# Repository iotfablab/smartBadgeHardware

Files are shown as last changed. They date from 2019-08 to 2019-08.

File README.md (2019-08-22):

# smartBadgeHardware
This repository holds the hardware design files for the iotfablab Smart Badge.

The hardware layout has been adapted from the "Sparkfun ESP-32-Thing Plus" (https://www.sparkfun.com/products/14689) and the "Waveshare e-Paper ESP32 Driver Board" (https://www.waveshare.com/e-paper-esp32-driver-board.htm).

It is designed to work with 
* the Waveshare 2.9 inch raw e-Paper Display (https://www.waveshare.com/2.9inch-e-Paper.htm) and 
* a 1 cell 3.7V LiPo battery with 2mm JST plug (e.g. https://www.exp-tech.de/zubehoer/batterien-akkus/lipo-akkus/9365/lipo-akku-750mah-3.7-v-2-mm-jst?c=1191).

# License
<br />This work is licensed under a <a rel="license" href="http://creativecommons.org/licenses/by-sa/4.0/">Creative Commons Attribution-ShareAlike 4.0 International License</a>.

# Contact
This project has been developed as an internal project of the IoT-Fablab (www.iotfablab.eu) at BIBA - Bremer Institut für Produktion und Logistik GmbH at the University of Bremen.

For more information on the project or our lab, please feel free to contact us via info@iotfablab.eu

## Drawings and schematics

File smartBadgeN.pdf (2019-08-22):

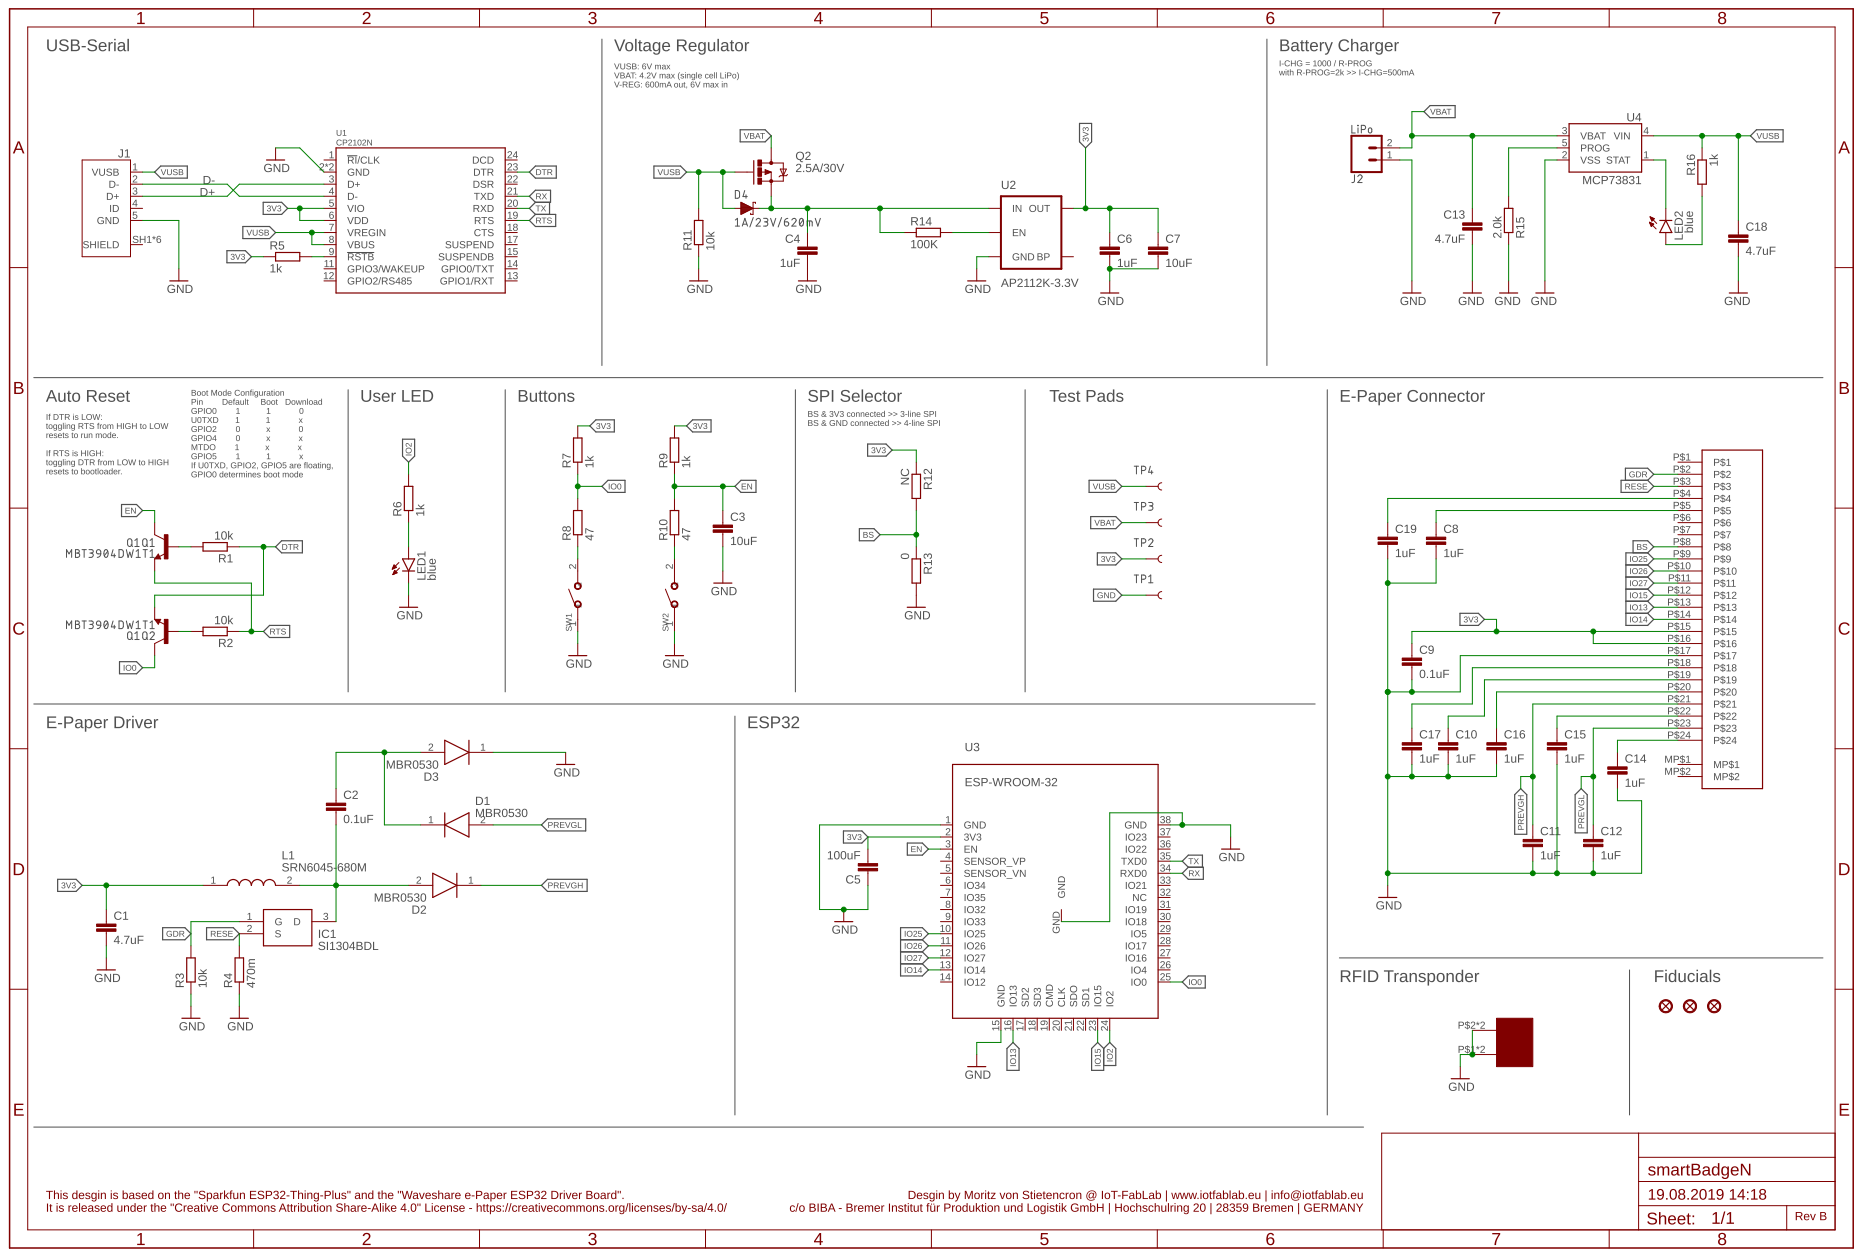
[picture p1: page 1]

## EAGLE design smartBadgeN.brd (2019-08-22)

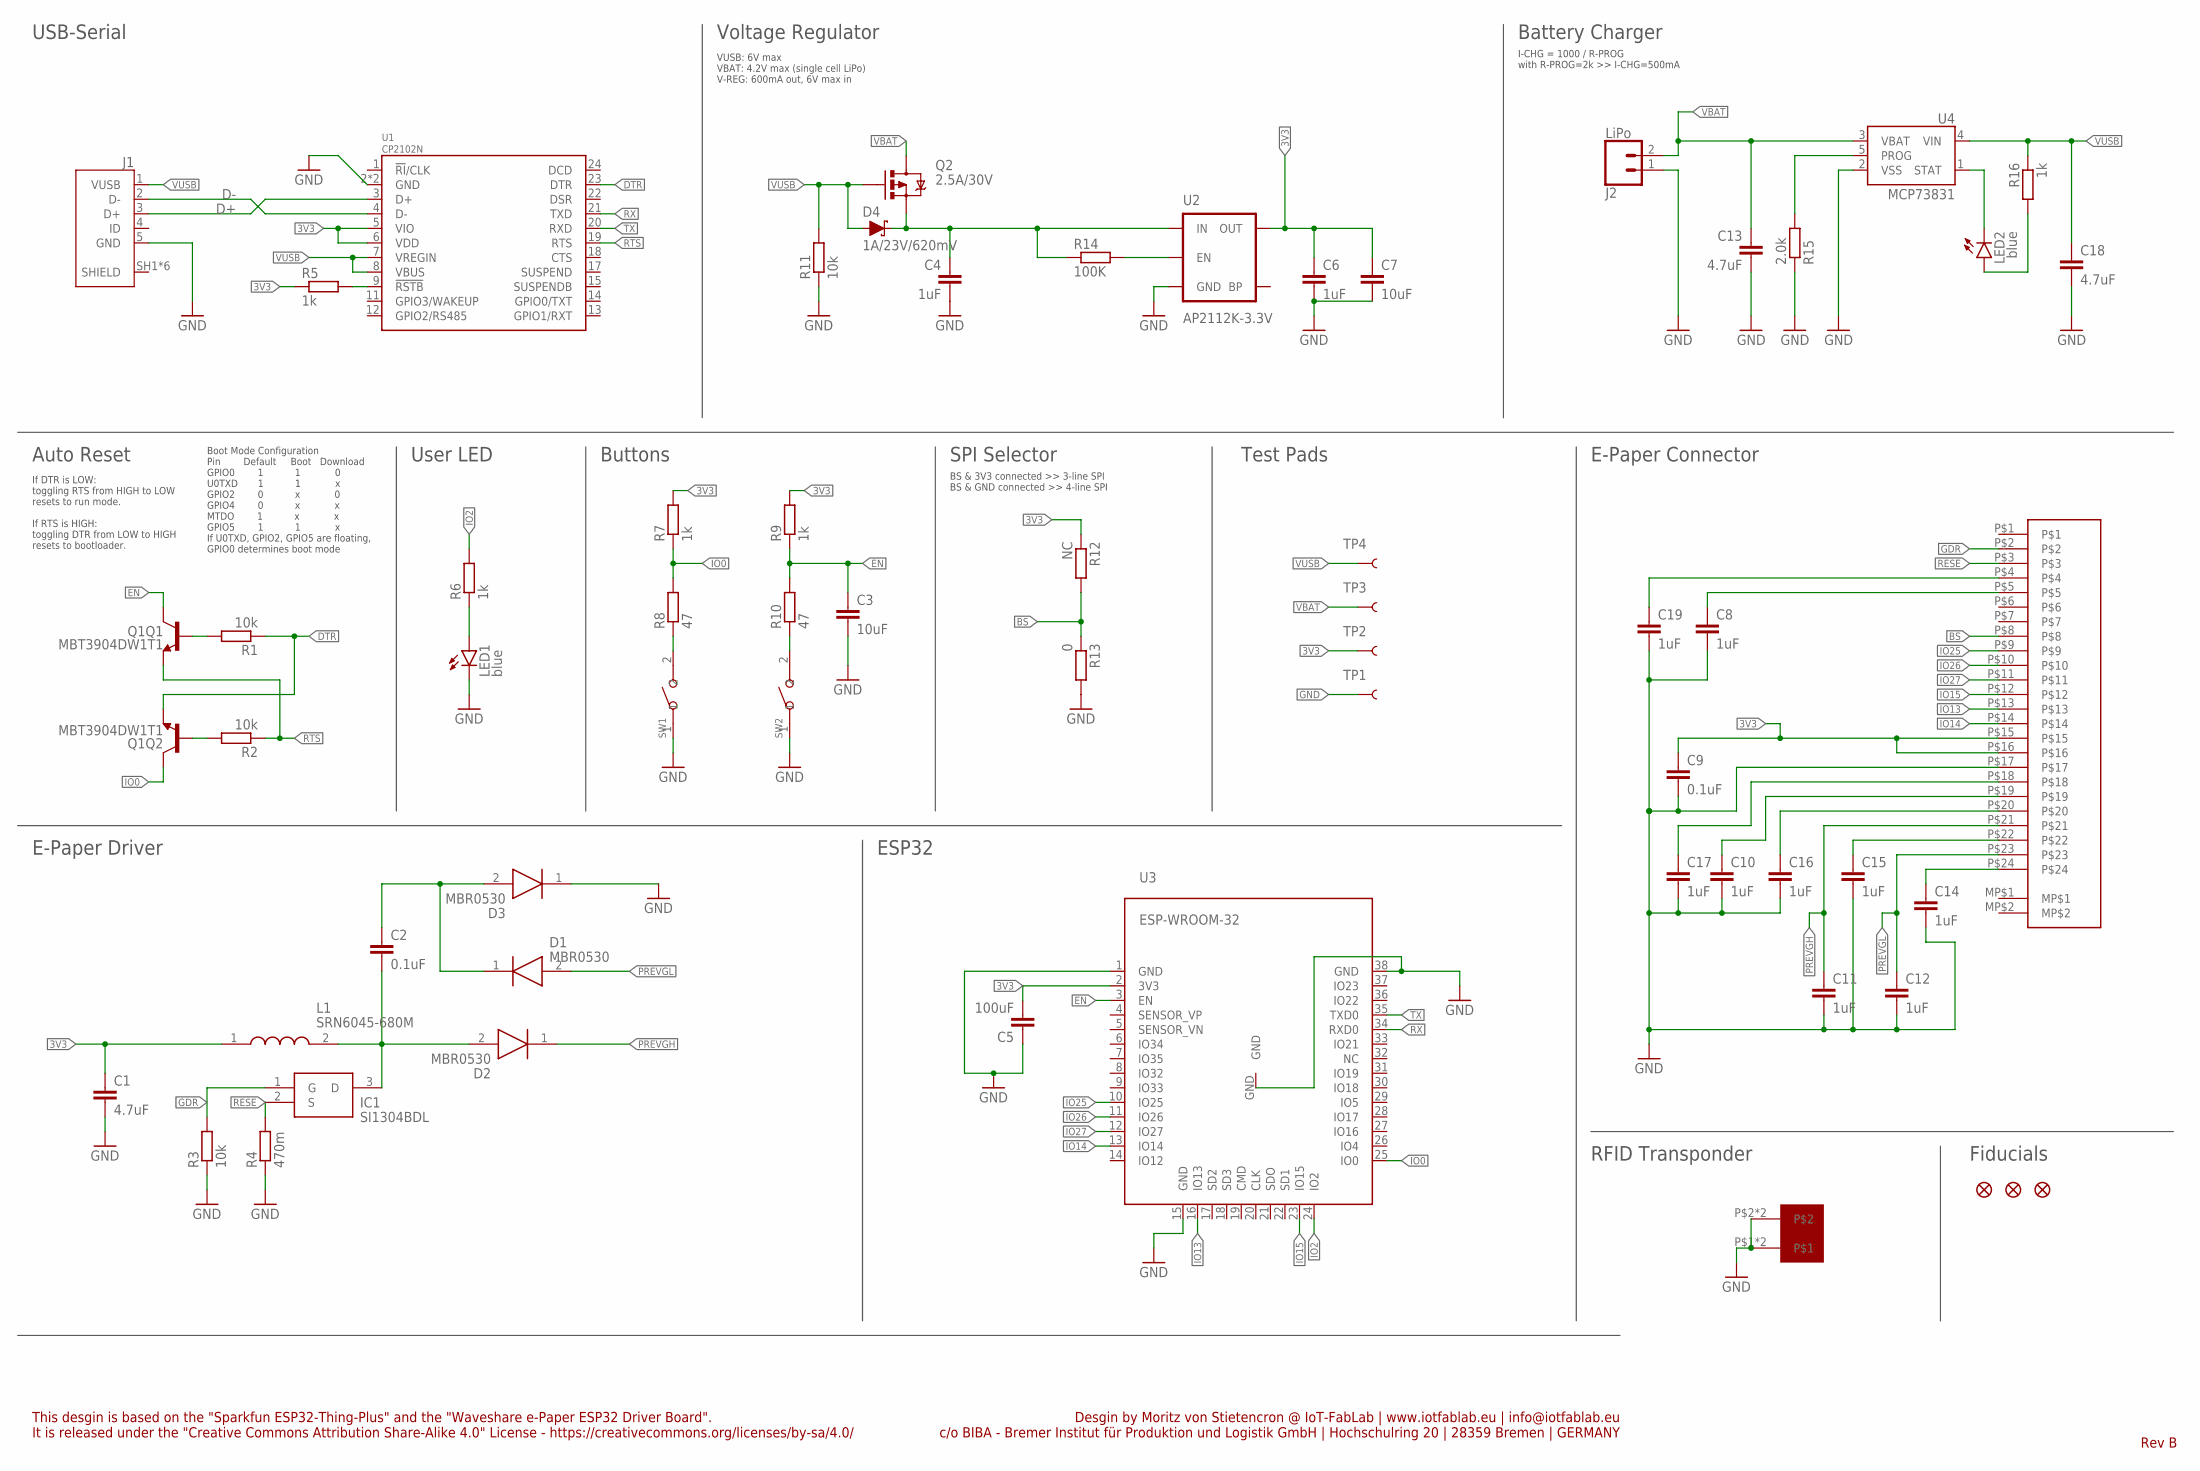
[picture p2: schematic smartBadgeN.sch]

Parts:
C1, C13, C18: 4.7uF; C0603
C2, C9: 0.1uF; C0603
C3, C7: 10uF; C0603
C4, C6, C8, C10, C11, C12, C14, C15, C16, C17, C19: 1uF; C0603
C5: 100uF; C1206
D1, D2, D3: MBR0530; SOD3716X135N
D4: 1A/23V/620mV; SOD-323
EPD: MOLEX-FPC-CONN-24X0.5; MOLEX-0512812494
FD1, FD2, FD3: FIDUCIAL1X2; FIDUCIAL-1X2
IC1: SI1304BDL; SOT65P210X110-3N
J1: 10118192-0001LF; AMPHENOL_10118192-0001LF
J2: LiPo; JST-2-SMD
L1: SRN6045-680M; INDPM6060X470N
LED1, LED2: blue; CHIP-LED0603
Q1: MBT3904DW1T1; SC70-6
Q2: 2.5A/30V; SOT23-3@1
R1, R2, R3, R11: 10k; R0603
R4: 470m; R0603
R5, R6, R7, R9, R16: 1k; R0603
R8, R10: 47; R0603
R12: NC; R0603
R13: 0; R0603
R14: 100K; R0603
R15: 2.0k; R0603
RFID1: LXMS21ACMF-183
SW1, SW2: SMD-BUTTON(2P-3.0X2.5X1.2+0.4MM)-B3U-1000P-2P-SMD; SW2-2.6-3.0X2.5X1.2+0.4MM
TP1, TP2, TP3, TP4: TEST-POINT3; PAD.03X.03
U1: CP2102N; QFN24
U2: AP2112K-3.3V; SOT23-5
U3: ESP-WROOM-32
U4: MCP73831; SOT23-5

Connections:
3V3: C1.1, C5.2, C6.1, C7.1, C9.1, EPD.P$15, EPD.P$16, L1.1, R5.1, R7.2, R9.2, R12.1, TP2.P$1, U1.5 (VIO), U1.6 (VDD), U2.5 (OUT), U3.2 (3V3)
BS: EPD.P$8, R12.2, R13.1
BTN1: R10.1, SW2.2
CHG: LED2.C, U4.1 (STAT)
D+: J1.3 (D+), U1.3 (D+)
D-: J1.2 (D-), U1.4 (D-)
DTR: Q1.1 (E), R1.1, U1.23 (DTR)
EN: C3.1, Q1.3 (C), R9.1, R10.2, U3.3 (EN)
EN1: R14.2, U2.3 (EN)
GDR: EPD.P$2, IC1.1 (G), R3.2
GND: C1.2, C3.2, C4.2, C5.1, C6.2, C7.2, C8.2, C9.2, C10.2, C11.2, C12.2, C13.2, C14.2, C15.2, C16.2, C17.2, C18.2, C19.2, D3.1 (K), EPD.P$17, J1.5 (GND), J2.1 (2), LED1.C, R3.1, R4.1, R11.1, R13.2, R15.1, RFID1.P$1, RFID1.P$2, RFID1.P$3, RFID1.P$4, SW1.1, SW2.1, TP1.P$1, U1.2 (GND), U1.PAD (GND), U2.2 (GND), U3.1 (GND), U3.15 (GND), U3.38 (GND), U3.GND, U4.2 (VSS)
IO0: Q1.6 (C), R7.1, R8.2, U3.25 (IO0)
IO2: R6.2, U3.24 (IO2)
IO13: EPD.P$13, U3.16 (IO13)
IO14: EPD.P$14, U3.13 (IO14)
IO15: EPD.P$12, U3.23 (IO15)
IO25: EPD.P$9, U3.10 (IO25)
IO26: EPD.P$10, U3.11 (IO26)
IO27: EPD.P$11, U3.12 (IO27)
unnamed: R5.2, U1.9 (!RSTB)
unnamed: C17.1, EPD.P$18
unnamed: C10.1, EPD.P$19
unnamed: LED2.A, R16.2
unnamed: R15.2, U4.5 (PROG)
unnamed: Q1.5 (B), R1.2
unnamed: LED1.A, R6.1
unnamed: C19.1, EPD.P$4
unnamed: C8.1, EPD.P$5
unnamed: C16.1, EPD.P$20
unnamed: C15.1, EPD.P$22
unnamed: C14.1, EPD.P$24
unnamed: C2.1, D1.1 (K), D3.2 (A)
unnamed: C2.2, D2.2 (A), IC1.3 (D), L1.2
unnamed: R8.1, SW1.2
unnamed: Q1.2 (B), R2.2
PREVGH: C11.1, D2.1 (K), EPD.P$21
PREVGL: C12.1, D1.2 (A), EPD.P$23
RESE: EPD.P$3, IC1.2 (S), R4.2
RTS: Q1.4 (E), R2.1, U1.19 (RTS)
RX: U1.21 (TXD), U3.34 (RXD0)
TX: U1.20 (RXD), U3.35 (TXD0)
VBAT: C13.1, J2.2 (1), Q2.3 (D), TP3.P$1, U4.3 (VBAT)
VIN: C4.1, D4.C, Q2.2 (S), R14.1, U2.1 (IN)
VUSB: C18.1, D4.A, J1.1 (VUSB), Q2.1 (G), R11.2, R16.1, TP4.P$1, U1.7 (VREGIN), U1.8 (VBUS), U4.4 (VIN)

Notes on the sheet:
USB-Serial
Voltage Regulator
Battery Charger
Auto Reset
User LED
E-Paper Connector
E-Paper Driver
SPI Selector
RFID Transponder
ESP32
Buttons
BS & 3V3 connected >> 3-line SPI BS & GND connected >> 4-line SPI
Fiducials
This desgin is based on the "Sparkfun ESP32-Thing-Plus" and the "Waveshare e-Paper ESP32 Driver Board". It is released under the "Creative Commons Attribution Share-Alike 4.0" License - https://creativecommons.org/licenses/by-sa/4.0/
Desgin by Moritz von Stietencron @ IoT-FabLab | www.iotfablab.eu | info@iotfablab.eu c/o BIBA - Bremer Institut für Produktion und Logistik GmbH | Hochschulring 20 | 28359 Bremen | GERMANY
Rev B
Test Pads
I-CHG = 1000 / R-PROG with R-PROG=2k >> I-CHG=500mA
VUSB: 6V max VBAT: 4.2V max (single cell LiPo) V-REG: 600mA out, 6V max in
If DTR is LOW: toggling RTS from HIGH to LOW resets to run mode. If RTS is HIGH: toggling DTR from LOW to HIGH resets to bootloader.
Boot Mode Configuration Pin Default Boot Download GPIO0 1 1 0 U0TXD 1 1 x GPIO2 0 x 0 GPIO4 0 x x MTDO 1 x x GPIO5 1 1 x If U0TXD, GPIO2, GPIO5 are floating, GPIO0 determines boot mode

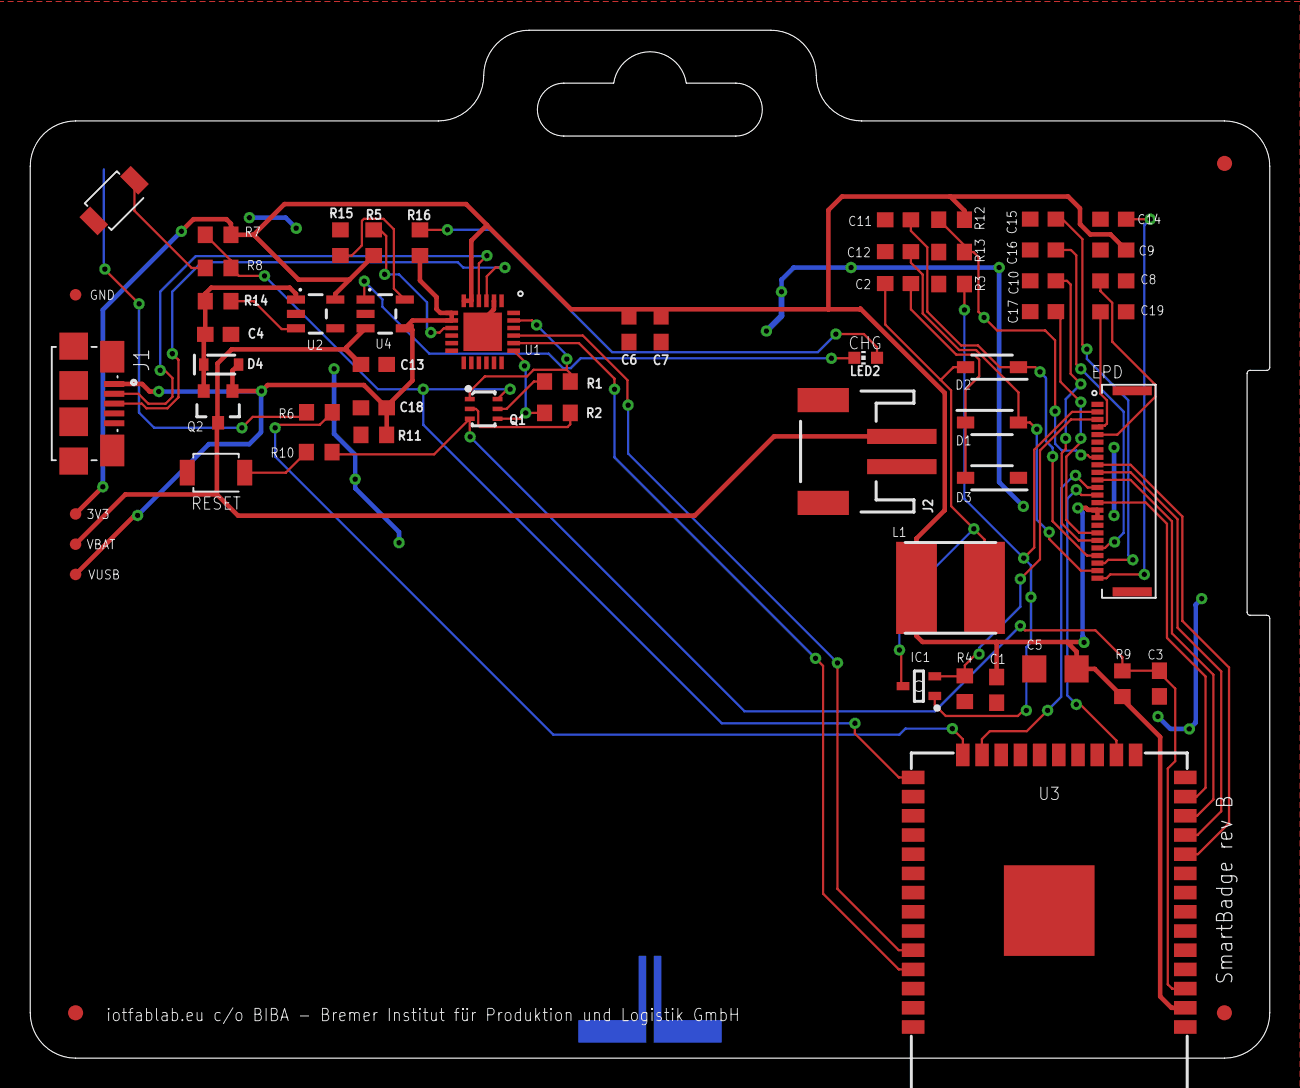
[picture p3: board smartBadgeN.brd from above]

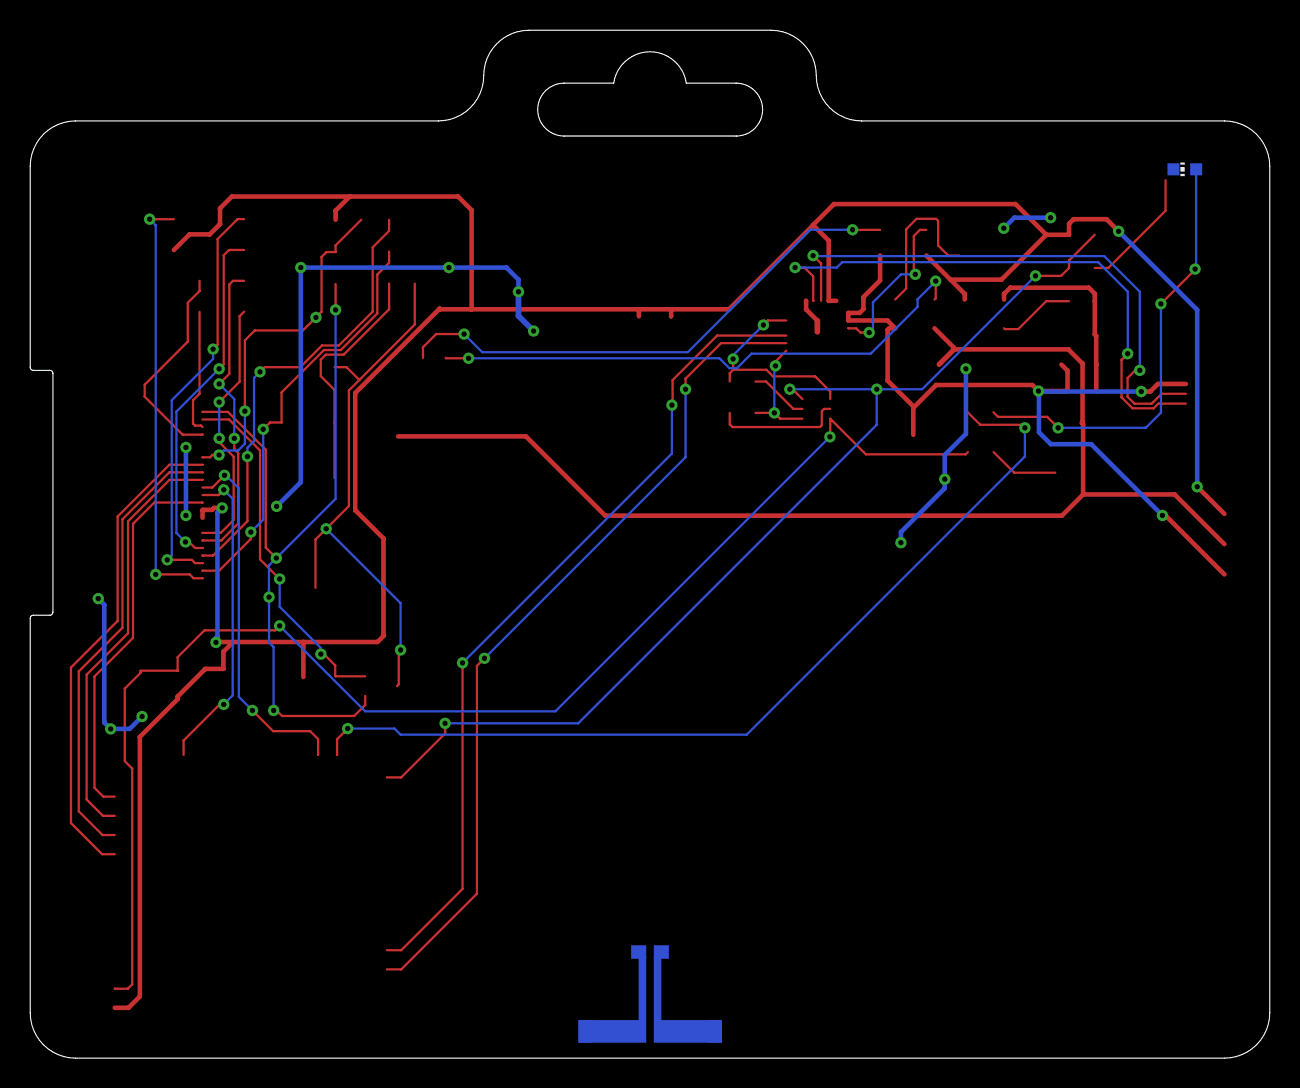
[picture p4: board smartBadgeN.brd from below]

Board: 2 copper layers, 82.0 x 68.0 mm, 62 parts (2 on the bottom side), 44 nets.

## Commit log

2019-06-06 hardware v1 commit
    [smartBadgeV1.brd, smartBadgeV1.sch]
2019-08-16 first batch
    [smartBadgeN.brd, smartBadgeN.sch]
2019-08-16 Deleted smartBadgeV1.brd, smartBadgeV1.pdf, smartBadgeV1.sch files
    [smartBadgeV1.brd, smartBadgeV1.sch]
2019-08-16 revB init
    [smartBadgeN.brd, smartBadgeN.sch]
2019-08-16 capacitor values updated
    [smartBadgeN.brd, smartBadgeN.sch]
2019-08-22 schematics pdf added
    [smartBadgeN.brd, smartBadgeN.sch]

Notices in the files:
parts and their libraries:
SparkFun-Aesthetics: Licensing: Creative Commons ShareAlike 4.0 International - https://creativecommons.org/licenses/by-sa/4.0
